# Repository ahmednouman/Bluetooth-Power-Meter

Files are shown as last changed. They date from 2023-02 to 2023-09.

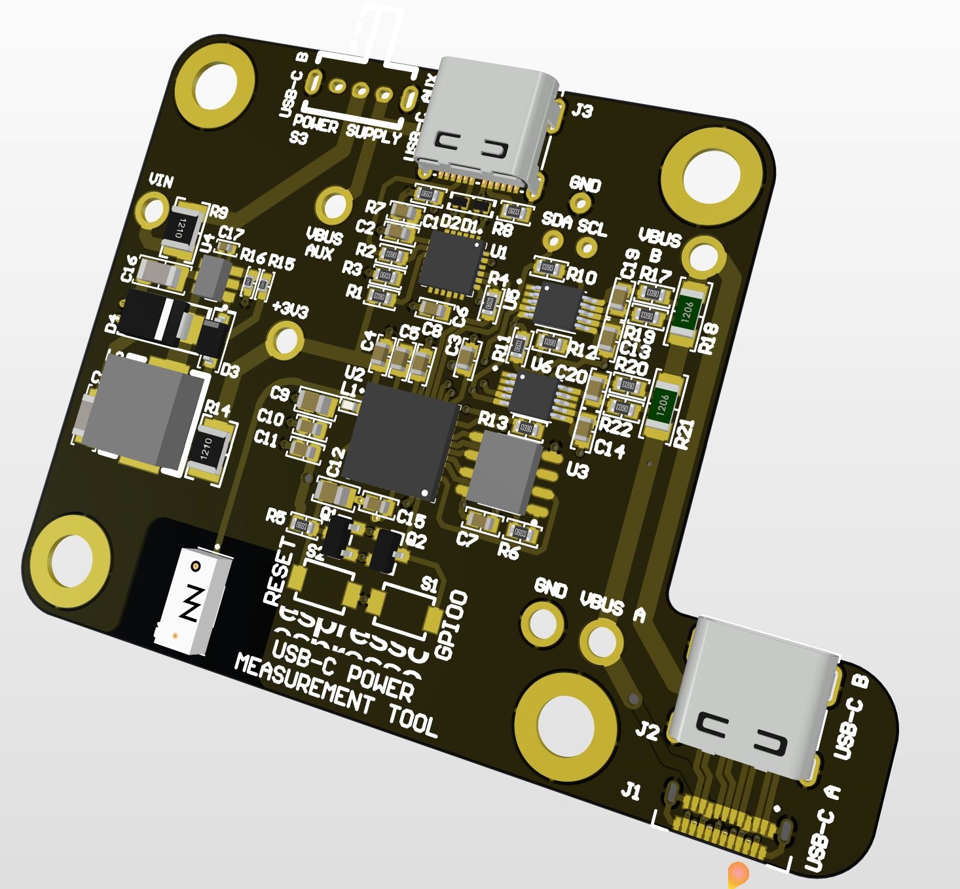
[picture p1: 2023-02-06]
images/3d.png

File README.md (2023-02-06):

# Bluetooth-Power-Meter
This is a 4-layer board (Power meter), designed to measure power(voltage & current) consumption of any USB-C device including USB-C video devices.
developed based on an ESP32-PICO-D4 MCU.
The board features:
- USB-C to USB-C data/video pass through
- Voltage and current measurement chips
- Chip Antenna design

<p align="center">

</p>

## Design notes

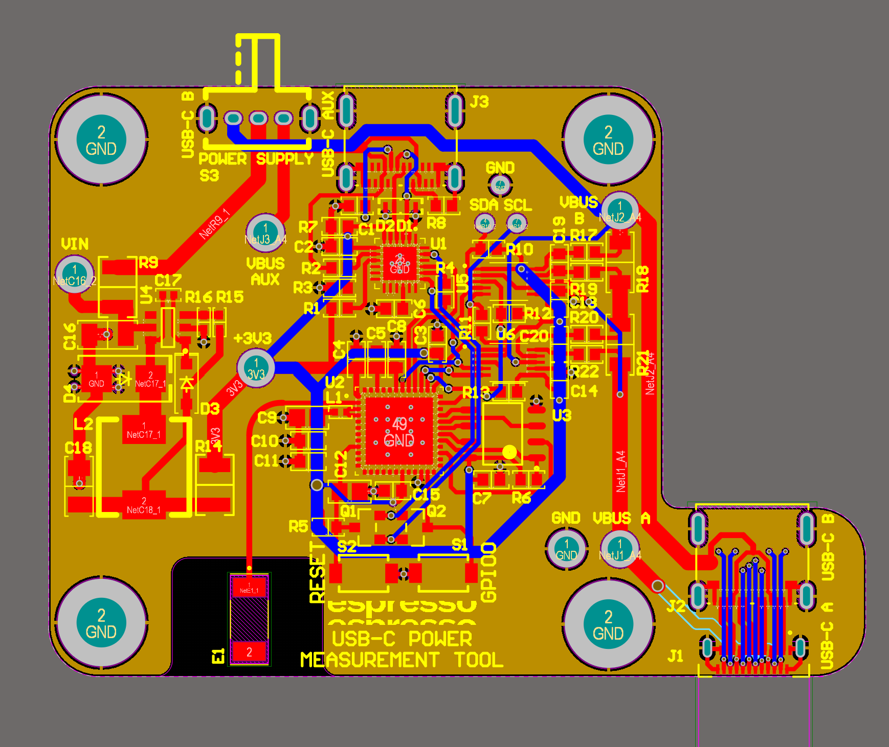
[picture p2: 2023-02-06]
images/tracks.png

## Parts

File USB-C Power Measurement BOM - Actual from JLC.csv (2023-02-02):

Uploaded BOM Data |  |  | Review Matched Parts
Top Designator | Comment | Footprint | Matched Part Detail
C5 | 100pF | CAP0603_1608 | CL10C101JB8NNNCC14858 50V 100pF C0G ±5% 0603 Multil...
C17 | CAPCER10000PF10... | CAPCER10000PF10... | CL05B103KB5NNNCC15195 50V 10nF X7R ±10% 0402 Multil...
R17,R19,R2... | 10Ohms | RES0603_1608 | 0603WAF100JT5EC22859 100mW Thick Film Resistors 75V...
R1 | 4.7kOhms | RES0603_1608 | 0603WAF4701T5EC23162 100MW THICK FILM RESISTORS 75V...
R7,R8 | 5.1kOhms | RES0603_1608 | 0603WAF5101T5EC23186 100MW THICK FILM RESISTORS 75V...
R4 | 510Ohms | RES0603_1608 | 0603WAF5100T5EC23193 100mW Thick Film Resistors 75V...
R2 | 24kOhms | RES0603_1608 | 0603WAF2402T5EC23352 100MW THICK FILM RESISTORS 75V...
R15 | 100kOhms | RES0402_1005 | 0402WGF1003TCEC25741 62.5mW Thick Film Resistors 50...
R5,R6,R10,... | 10kOhms | RES0603_1608 | 0603WAF1002T5EC25804 100MW THICK FILM RESISTORS 75V...
R3 | 47kOhms | RES0603_1608 | 0603WAF4702T5EC25819 100MW THICK FILM RESISTORS 75V...
R16 | 32.4kOhms | RES0402_1005 | 0402WGF3242TCEC26974 62.5MW THICK FILM RESISTORS 50...
C1,C3,C4,C... | 0.1礔 | CAP0603_1608 | 0603B104K500NTC30926 50V 100NF X7R ±10% 0603 MULTI...
C9,C12 | 10礔 | CAP0805_2012 | 0805X106K250NTC40894 25V 10UF X5R ±10% 0805 MULTIL...
U5,U6 | INA226AIDGSR | SOP50P490X110-1... | INA226AIDGSRC49851 MSOP-10 Current-Sensing Ampli...
C6 | 4.7礔 | CAP0603_1608 | 0603X475K100NTC69182 10V 4.7UF X5R ±10% 0603 MULTI...
U4 | RT8258GE | SOT100P279X130-... | RT8258GEC77574 SOT-23-6 DC-DC Converters ROH...
D3 | 1N4148W-TP | SOD-123 | 1N4148W-TPC77978 100V -65℃~+150℃@(Tj) 400mW 1.2...
D1,D2 | LXES15AAA1-153 | 402 | LXES15AAA1-153C86141 4V Bidirectional 0402 ESD Pro...
Q1,Q2 | MMSS8050-H-TP | MCCSEMISOT-23-3 | MMSS8050-H-TPC90158 100nA 300mW 1.5A 200@100mA,1V ...
C2,C7,C8,C... | 1礔 | CAP0603_1608 | 0603B105K500NTC90540 50V 1UF X7R ±10% 0603 MULTILA...
C18 | 22礔 | CAP1206_3216-0.... | 1206X226K160NTC105480 16V 22UF X5R ±10% 1206 MULTIL...
D4 | B230-13-F | DO214AASMB | B230-13-FC110482 30V 500mV@2A 2A SMB(DO-214AA) ...
C16 | 10礔 | CAP1206_3216-0.... | 1206X106K500NTC116702 50V 10UF X5R ±10% 1206 MULTIL...
J2,J3 | 1054500101 | Molex1054500101 | 1054500101C134092 1 24 Female Type-C SMD USB Co...
S3 | SK-12D02-VG5 | SK-12D02-VG5 | SK-12D02-VG5C136722 Lying SPDT 9.5mm PCPin 5000 Re...
U2 | ESP32-PICO-D4 | PQFN50P700X700X... | ESP32-PICO-D4C193707 QFN-48_7x7x05P RF Transceiver...
R9,R14 | 0Ohms | RES1210_3225 | ERJ14Y0R00UC242155 500mW ±200ppm/℃ -55℃~+155℃ 0Ω ...
U3 | LY68L6400 | SOP-8_3.9x4.9x1... | LY68L6400SLITC261881 SOP-8_150mil SRAM ROHS
L1 | FIXEDIND2NH1A50... | IND0402_1005 | 0402CP-2N0G-LRHC346262 1.04A 2NH ±2% 70MΩ 0402 INDUC...
U1 | CP2104-F03-GM | QFN50P400X400X8... | CP2104-F03-GMC430013 QFN-24 USB ICs ROHS
R18,R21 | 2mOhms | STACKPOLECSR120... | HoLR1206-1W-2mR-1%-75ppmC601094 1W 2MΩ ±75PPM/℃ ±1% 1206 CURR...
S1,S2 | GT-TC029B-H025-... | GT-TC029B-H025-... | GT-TC029B-H025-L1NC843669 No NO SMDSplicing 50mA 3.9mm 1...
L2 | 4A10uH�20%67mOS... | 4A10uH�20%67mOS... | TMPC0624H-100M-Z01-DC2880075 3.2A 10uH ±20% 92mΩ 5A SMD,7x6...
E1 | NN01-102 | XCVR_NN01-102 | NN01-102C9900010288 2.45GHz Bluetooth, WLAN, Zigbe...
J1 | USB4155-03-C_RE... | GCT_USB4155-03-... | No part selected Search

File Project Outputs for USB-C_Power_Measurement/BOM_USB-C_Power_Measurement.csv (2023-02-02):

Comment | Description | Designator | Footprint | LibRef | Quantity
0.1 µF | CAP CER 0.1UF 50V X7R 0603 | C1, C3, C4, C11, C13, C14, C15, C19, C20 | CAP 0603_1608 | C0603C104K5RAC7411 | 9
1 µF | CAP CER 1UF 10V X7R 0603 | C2, C7, C8, C10 | CAP 0603_1608 | CC0603KRX7R6BB105 | 4
100 pF | CAP CER 100PF 50V C0G/NP0 0603 | C5 | CAP 0603_1608 | C0603C101K5GACAUTO | 1
4.7 µF | CAP CER 4.7UF 16V X7R 0603 | C6 | CAP 0603_1608 | GRM188Z71C475KE21J | 1
10 µF | CAP CER 10UF 6.3V X7R 0805 | C9, C12 | CAP 0805_2012 | CGA4J1X7R0J106K125AC | 2
10 µF | CAP CER 10UF 25V X7R 1206 | C16 | CAP 1206_3216 - 0.8MM | GRM31CR71E106MA12K | 1
10000 pF | CAP CER 10000PF 10V X7R 0402 | C17 | CAP 0402_1005 | VJ0402Y103JXQCW1BC | 1
22 µF | CAP CER 22UF 6.3V X7R 1206 | C18 | CAP 1206_3216 - 0.8MM | GCM31CR70J226KE23L | 1
LXES15AAA1-153 | TVS DIODE 4V 1005 | D1, D2 | 0402 | LXES15AAA1-153 | 2
1N4148W-TP | DIODE GEN PURP 100V 150MA SOD123 | D3 | SOD-123 | 1N4148W-TP | 1
B230-13-F | DIODE SCHOTTKY 30V 2A SMB | D4 | DO214AA SMB | B230-13-F | 1
NN01-102 | 2.45GHz Bluetooth, WLAN, Zigbee Chip RF Antenna 2.4GHz ~ 2.5GHz 1.7dBi Solder Surface Mount | E1 | XCVR_NN01-102 | NN01-102 | 1
USB4155-03-C_REVA |  | J1 | GCT_USB4155-03-C_REVA | USB4155-03-C_REVA | 1
1054500101 | CONN RCP USB3.1 TYPEC 24P SMD RA | J2, J3 | Molex 1054500101 | 1054500101 | 2
2 nH | FIXED IND 2NH 1A 50 MOHM SMD | L1 | IND 0402_1005 | MHQ1005P2N0BT000 | 1
10uH | 4A 10uH ±20% 67mO SMD,7x6.6x2.8mm Power Inductors ROHS | L2 | 0630CDMCCDS-100MC | 0630CDMCCDS-100MC | 1
MMSS8050-H-TP | TRANS NPN 25V 1.5A SOT23 | Q1, Q2 | MCCSEMI SOT-23-3 | MMSS8050-H-TP | 2
4.7 kOhms | RES SMD 4.7K OHM 1% 1/10W 0603 | R1 | RES 0603_1608 | RT0603FRE074K7L | 1
24 kOhms | RES 24K OHM 1% 1/10W 0603 | R2 | RES 0603_1608 | RK73H1JTTD2402F | 1
47 kOhms | RES SMD 47K OHM 1% 1/10W 0603 | R3 | RES 0603_1608 | RT0603FRE0747KL | 1
510 Ohms | RES 510 OHM 5% 1/10W 0603 | R4 | RES 0603_1608 | RMCF0603JT510R | 1
10 kOhms | RES SMD 10K OHM 5% 1/4W 0603, RES 10K OHM 0.1% 1/16W 0603 | R5, R6, R10, R11, R12, R13 | RES 0603_1608 | RCS060310K0JNEA, RNCS0603BKE10K0 | 6
5.1 kOhms | RES 5.1K OHM 5% 1/10W 0603 | R7, R8 | RES 0603_1608 | RK73B1JTTD512J | 2
0 Ohms | RES 0 OHM JUMPER 1/2W 1210 | R9, R14 | RES 1210_3225 | RC1210JR-070RL | 2
100 kOhms | RES 100K OHM 0.1% 1/10W 0402 | R15 | RES 0402_1005 | RP73PF1E100KBTD | 1
32.4 kOhms | RES SMD 32.4KOHM 0.1% 1/16W 0402 | R16 | RES 0402_1005 | CPF0402B32K4E1 | 1
10 Ohms | RES SMD 10 OHM 0.1% 1/10W 0603 | R17, R19, R20, R22 | RES 0603_1608 | CRT0603-BY-10R0ELF | 4
2 mOhms | 1W 0.002 OHMS 1% 1206 | R18, R21 | STACKPOLE CSR1206 | PCS1206FR0020ET | 2
GT-TC029B-H025-L1N | No NO SMDSplicing 50mA 3.9mm 100MO 100000 12V 250gf@±30gf 2.9mm -30?~+85? 2.5mm Black Round Button Brick nogging SPST SMD Tactile Switches ROHS | S1, S2 | GT-TC029B-H025-L1N | GT-TC029B-H025-L1N | 2
SK-12D02-VG5 | Lying SPDT 9.5mm PCPin 5000 Rectangular columnar -25?~+70? Plugin Slide Switches ROHS SP#C136722 | S3 | SK-12D02-VG5 | SK-12D02-VG5 | 1
CP2104-F03-GM | USB-to-UART 1-CH 576byte FIFO 3.3V 24-Pin QFN EP T/R | U1 | QFN50P400X400X80-25N | CP2104-F03-GM | 1
ESP32-PICO-D4 | Bluetooth, WiFi 802.11b/g/n, Bluetooth v4.2 +EDR, Class 1, 2 and 3 Transceiver Module 2.4GHz ~ 2.5GHz Surface Mount | U2 | PQFN50P700X700X104-49N | ESP32-PICO-D4 | 1
LY68L6400 | 64M Bits Serial Pseudo-SRAM with SPI and QPI | U3 | SOP-8_3.9x4.9x1.27P | LY68L6400SLIT | 1
RT8258GE | RICHTEK 1.2A, 24V, 700kHz Step-Down Converter SOT23-6 | U4 | SOT100P279X130-6N | RT8258GE | 1
INA226AIDGSR |  | U5, U6 | SOP50P490X110-10N | INA226AIDGSR | 2

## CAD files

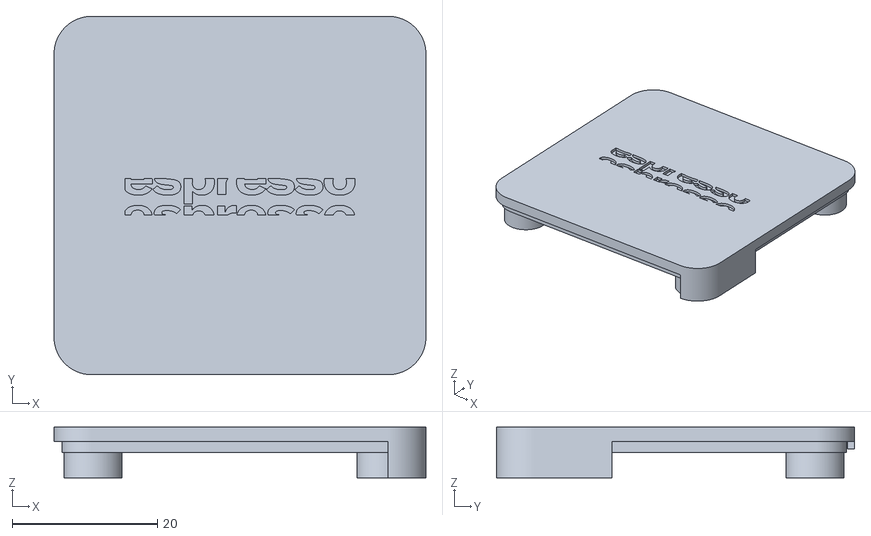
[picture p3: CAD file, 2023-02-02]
PCB_Power_Measurement_2.stl
51.2 x 49.4 x 7.00

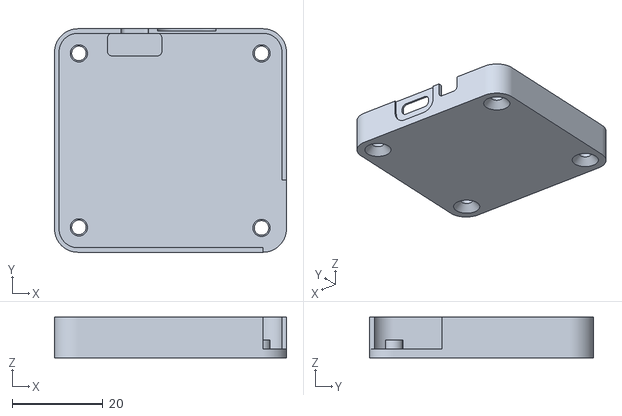
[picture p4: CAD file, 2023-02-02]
PCB_Power_Measurement_1.stl
51.2 x 49.4 x 9.00

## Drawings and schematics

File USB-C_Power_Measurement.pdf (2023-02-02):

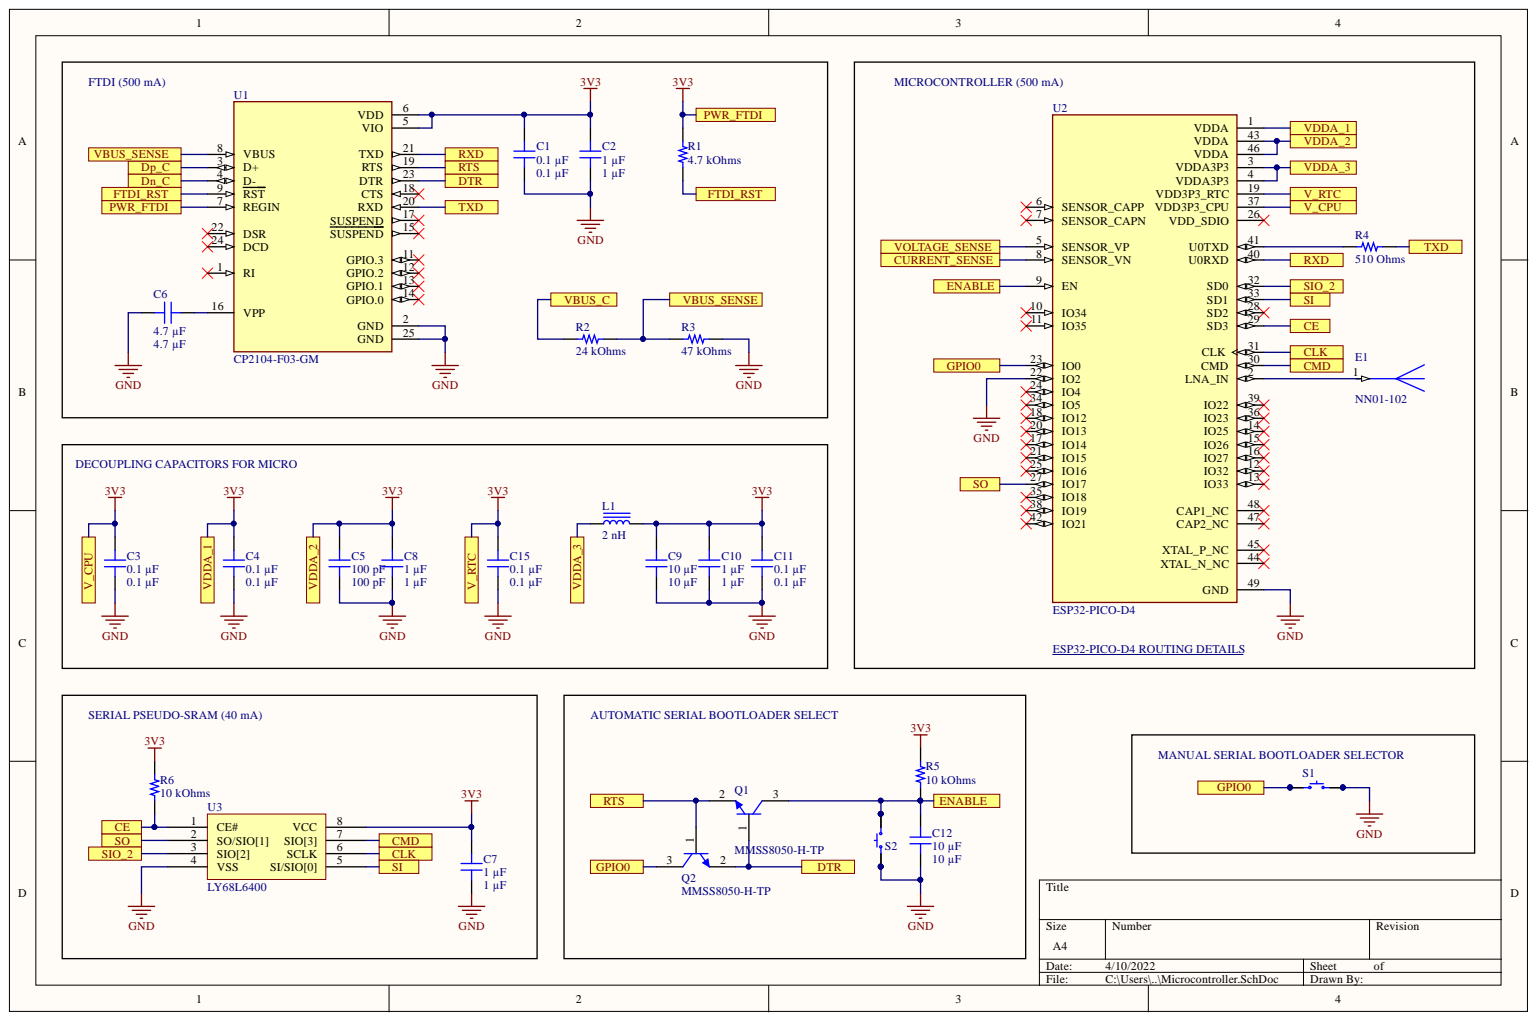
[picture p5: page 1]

DECOUPLING CAPACITORS FOR MICRO

SERIAL PSEUDO-SRAM (40 mA)

AUTOMATIC SERIAL BOOTLOADER SELECT

MANUAL SERIAL BOOTLOADER SELECTOR

SO | CMD
SIO_2 | CLK

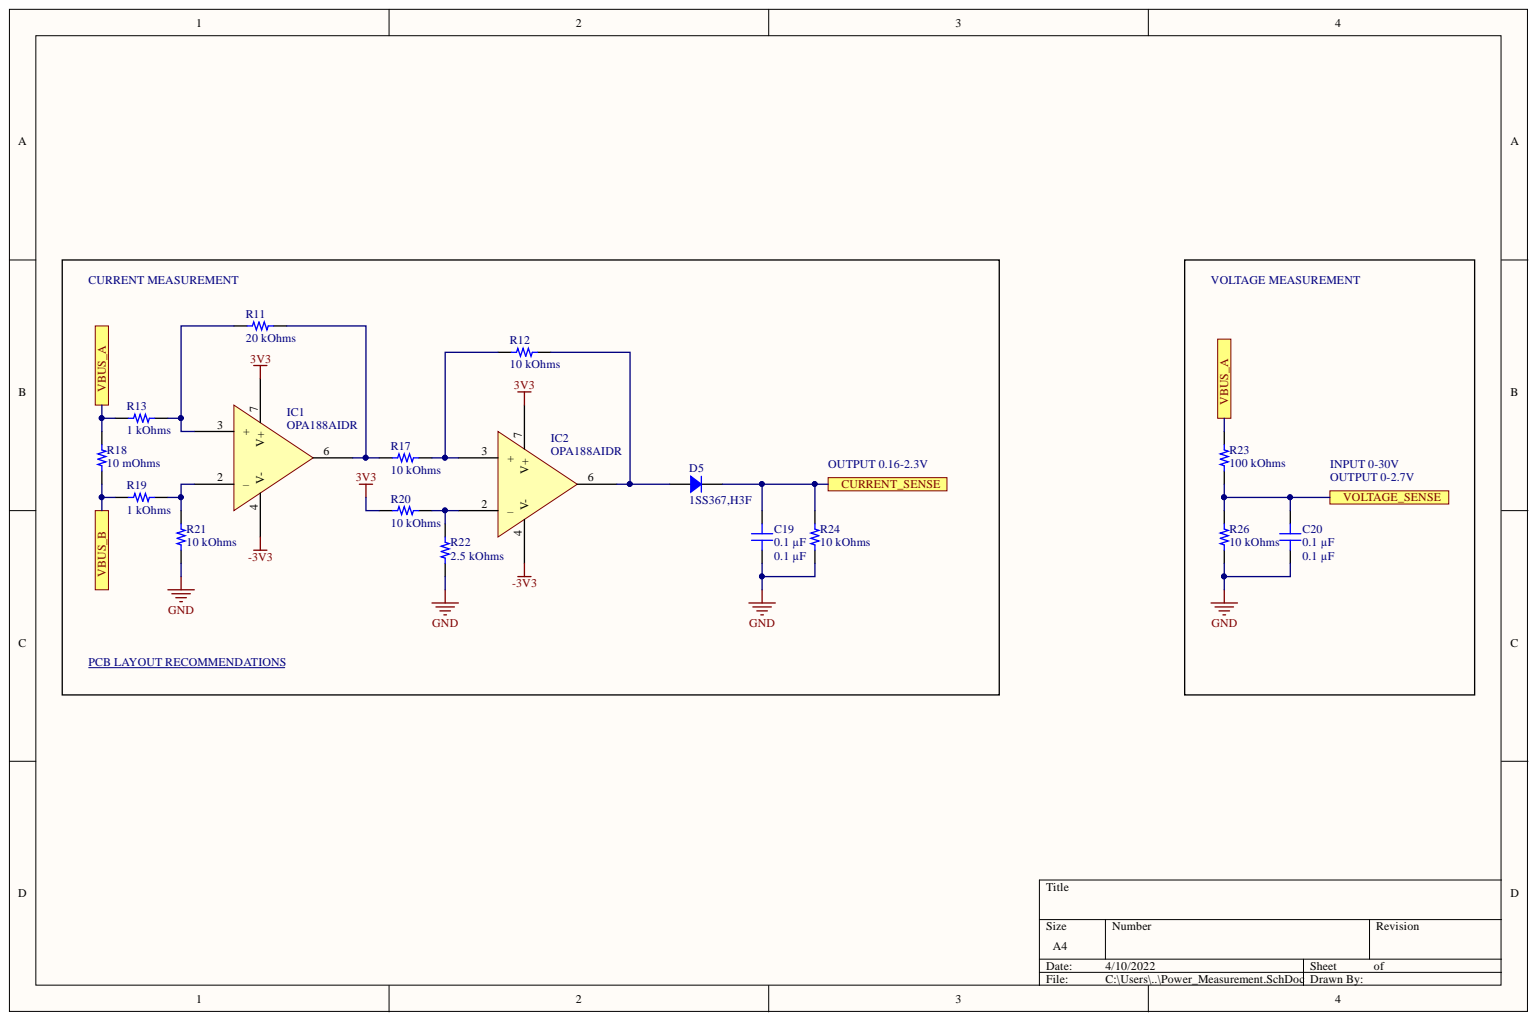
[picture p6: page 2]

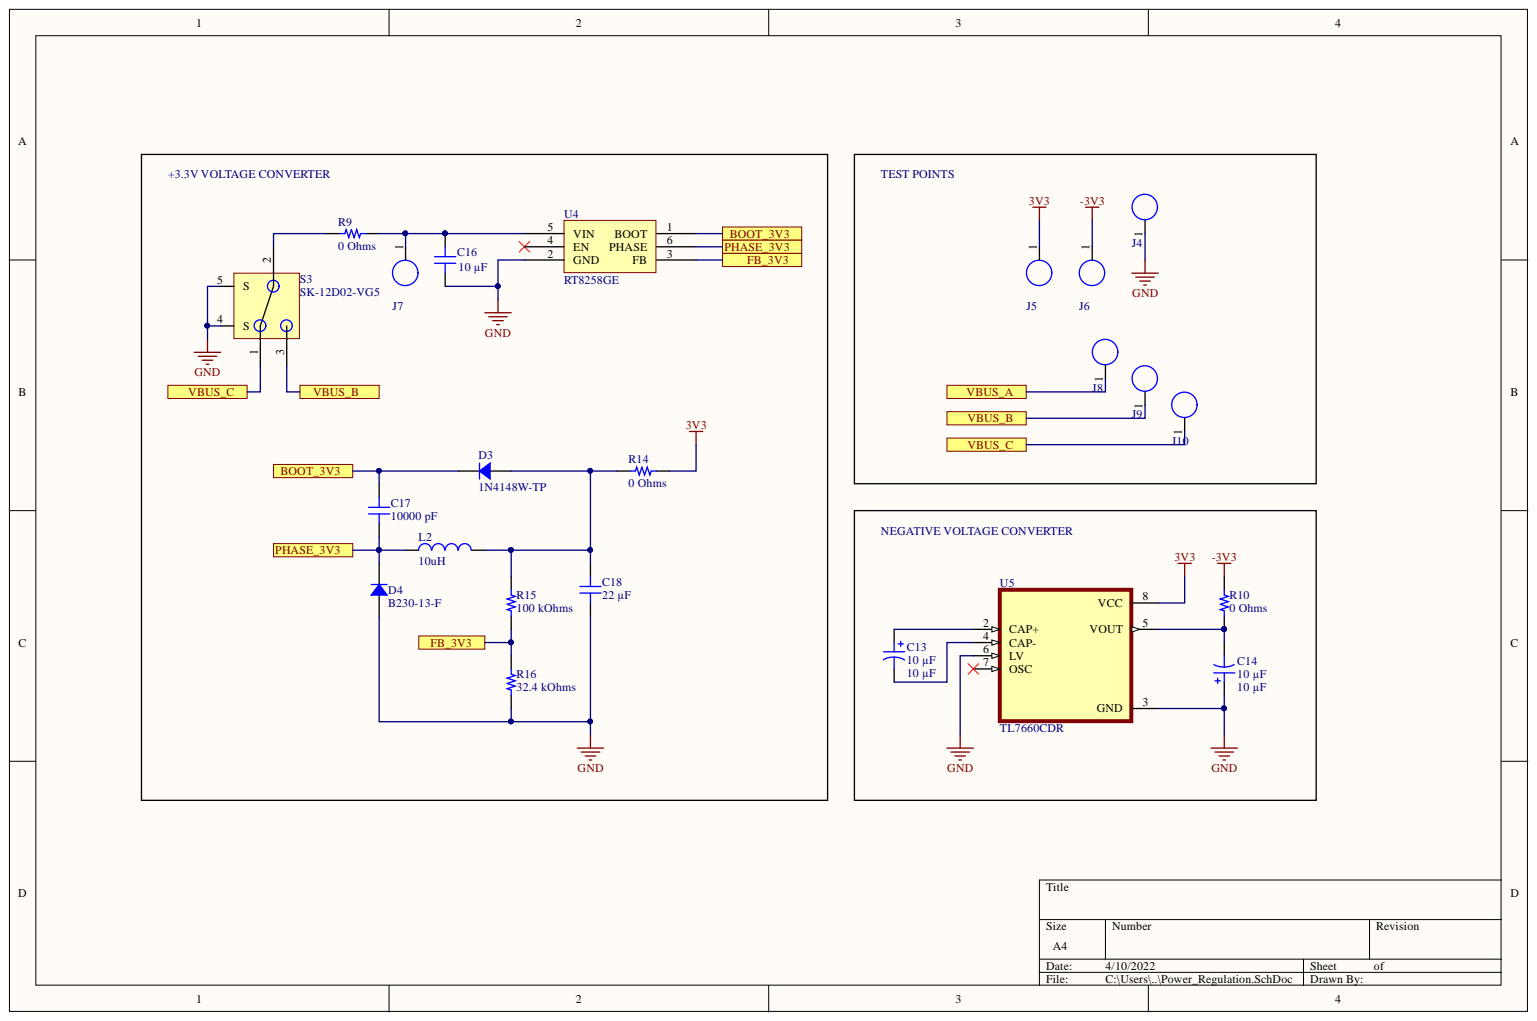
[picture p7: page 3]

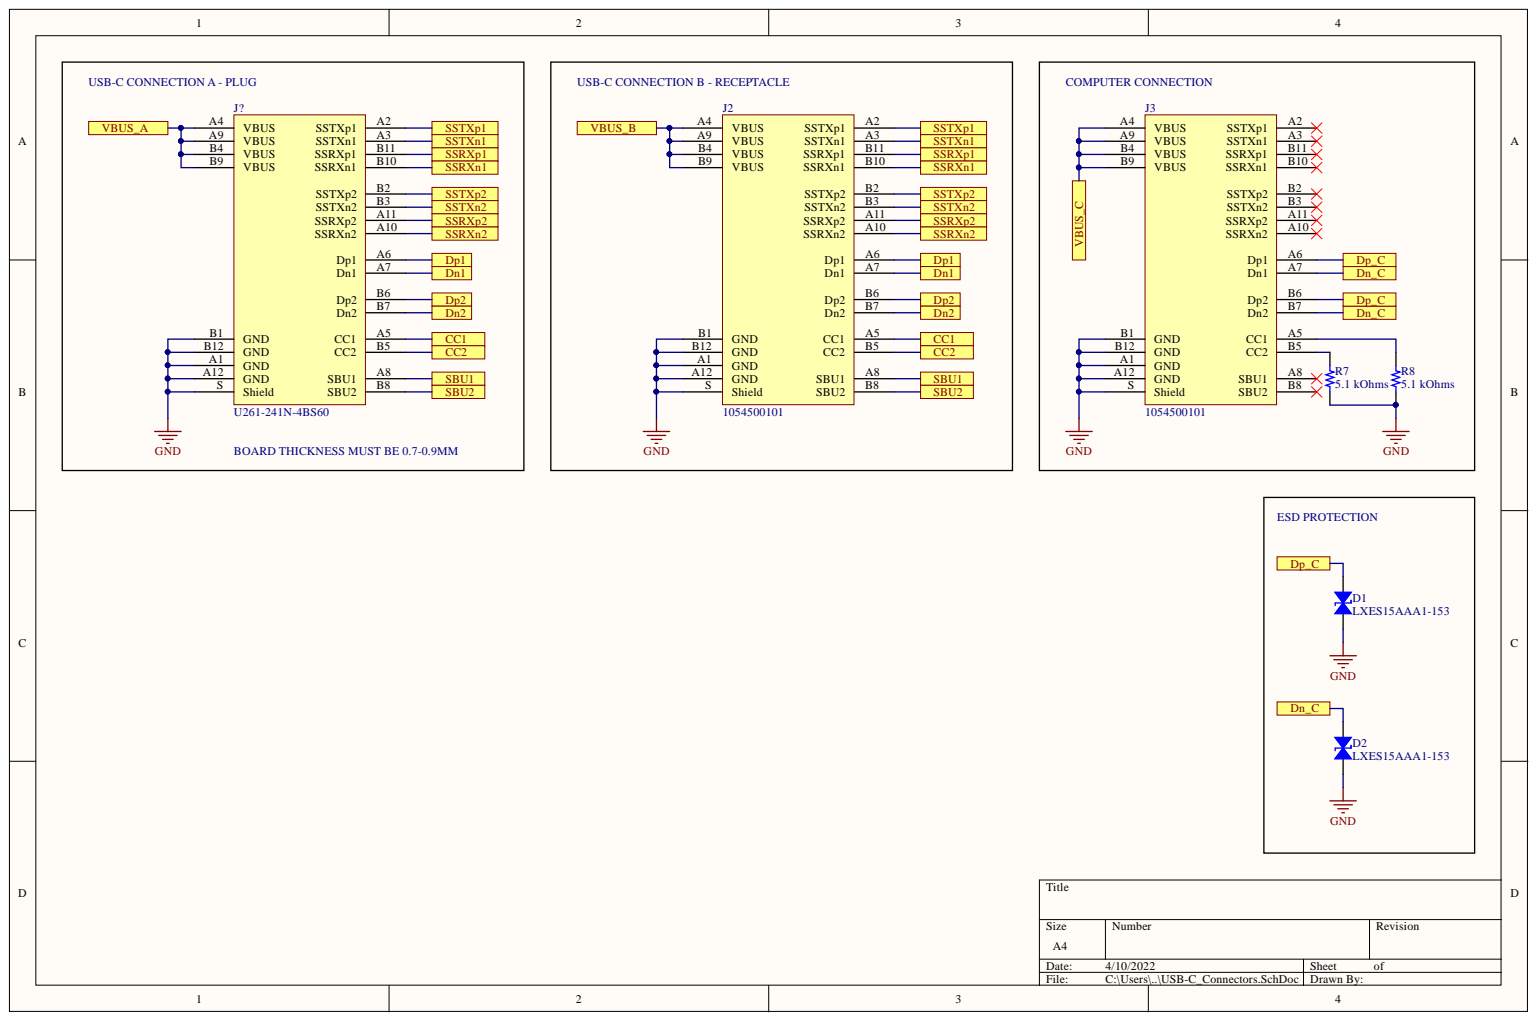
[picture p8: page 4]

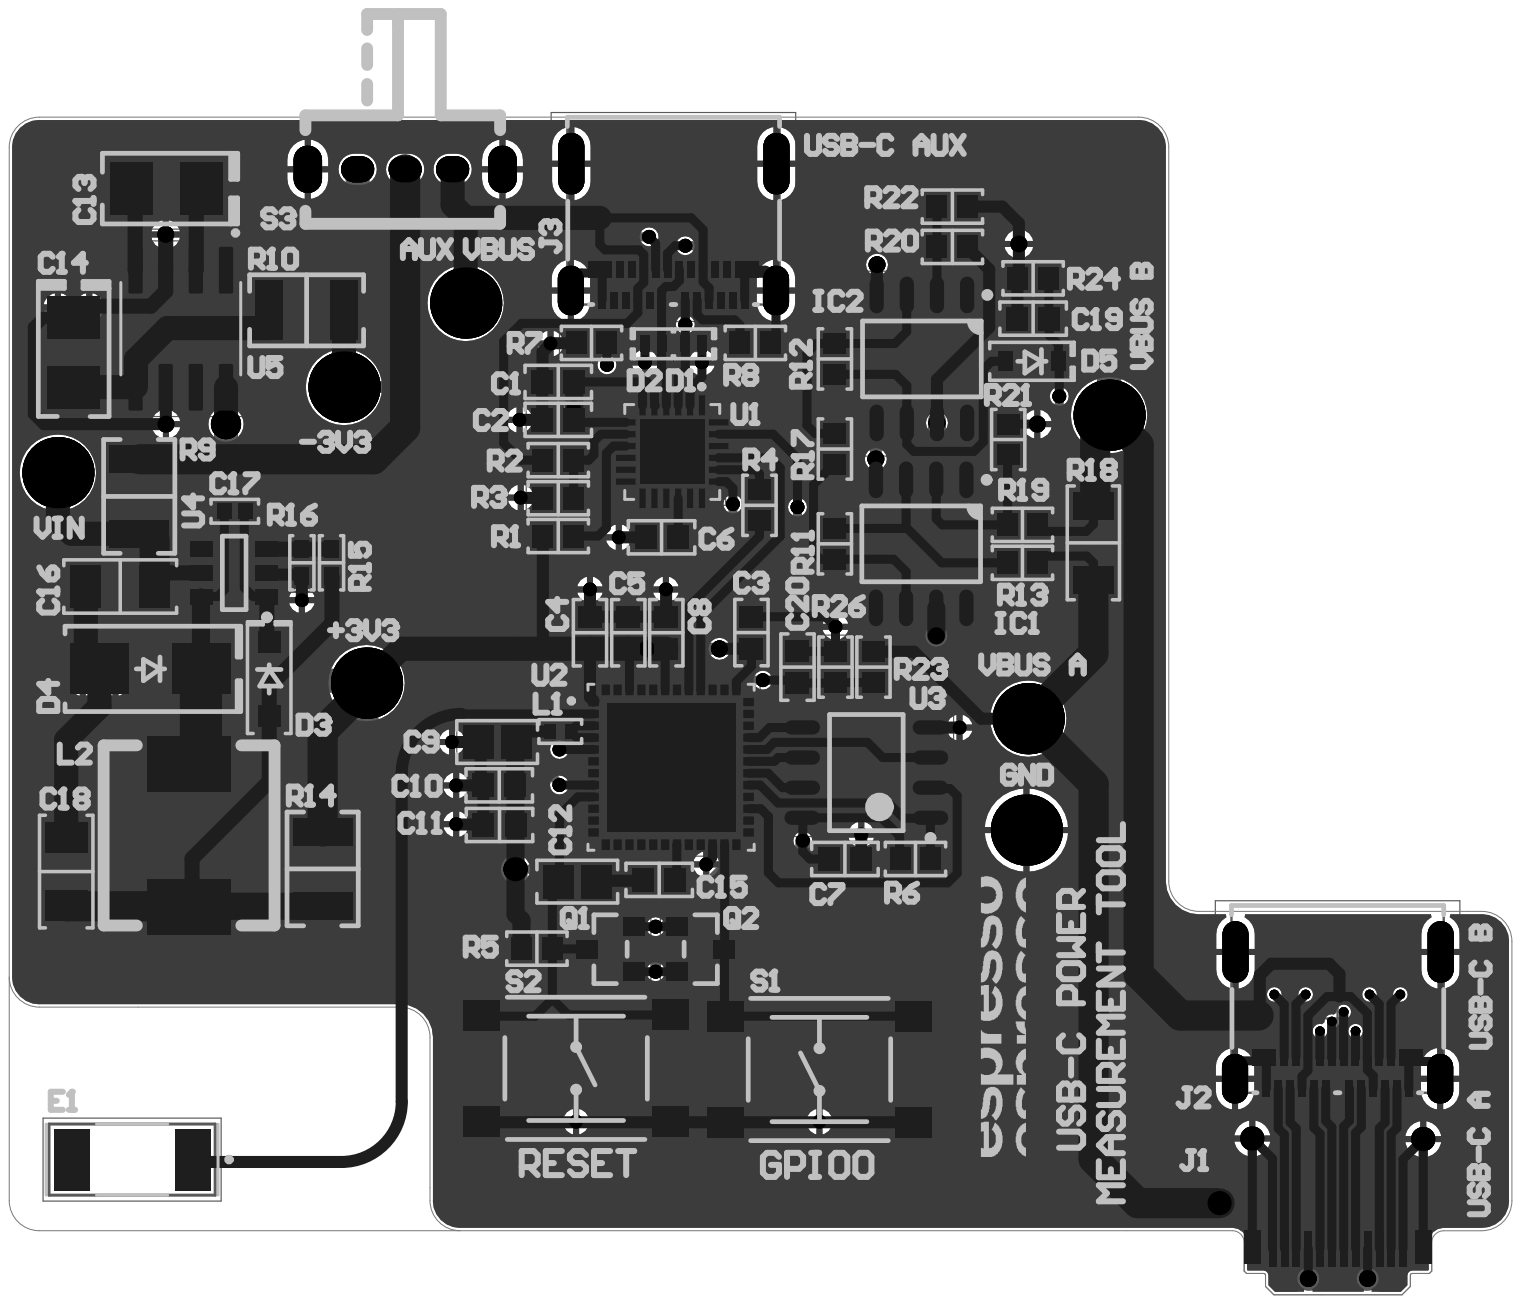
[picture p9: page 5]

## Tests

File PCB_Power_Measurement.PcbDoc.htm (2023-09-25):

Reporting Options

# File in Previous Format

Date | : | 7/1/2023
Time | : | 1:39:22 PM
Filename | : | C:\Espresso\PersonalHub\Bluetooth-Power-Meter\PCB_Power_Measurement.PcbDoc

Version | Warning

This file was generated by an earlier version of the software

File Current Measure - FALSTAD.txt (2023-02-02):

$ 1 0.000005 10.20027730826997 50 5 43 5e-11
r 32 192 32 272 0 0.01
w 32 128 32 192 1
w 336 208 336 128 0
w 208 128 112 128 0
w 112 128 112 192 0
r 112 192 32 192 0 1000
r -32 224 -32 336 0 4
w 32 272 32 336 0
r 336 128 208 128 0 20000
w 336 208 464 208 3
r 32 272 112 272 0 1000
w 112 224 112 272 0
r 112 272 112 352 0 10000
g 112 352 112 400 0 0
409 224 208 320 208 1 0.8 -1.424897561023406 0.016 0
w 112 192 224 192 3
w 112 224 224 224 3
w 320 208 336 208 0
R 272 320 272 352 0 0 40 -3.3 0 0 0.5
w 272 240 272 320 1
R 272 176 272 144 0 0 40 3.3 0 0 0.5
v -32 128 -32 224 0 0 40 30 0 0 0.5
409 544 224 704 224 1 0.8 -5.297524655984678 0.016 0
R 624 192 624 144 0 0 40 3.3 0 0 0.5
R 624 320 624 352 0 0 40 -3.3 0 0 0.5
r 368 240 432 240 0 10000
r 544 240 544 336 0 2500
g 544 336 544 368 0 0
R 368 240 336 240 0 0 40 3.3 0 0 0.5
r 464 208 544 208 0 10000
w 544 208 544 96 0
r 544 96 704 96 0 10000
w 704 96 704 224 0
w -32 336 32 128 0
w -32 128 32 336 0
w 624 256 624 320 1
r 800 224 800 304 0 10000
g 800 304 800 336 0 0
w 432 240 544 240 3
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
34 1SS357,H3F 0 0.000019999999999999998 0.084 1.7699694593 10 0
d 752 224 800 224 2 1SS357,H3F
w 704 224 752 224 3
o 41 16 0 4099 2.5 0.00009765625 0 2 41 3

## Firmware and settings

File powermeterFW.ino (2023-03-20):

#include "INA226.h"
#include "Wire.h"

#include <BLEDevice.h>
#include <BLEUtils.h>
#include <BLEServer.h>
#include <BLEAdvertising.h>

INA226 INA(0x45);

char txValue = 0;
float voltage = 0;
float current = 0;
float wattage = 0;

#include "esp_err.h"
#include "esp_pm.h"
#include "driver/timer.h"

#define SERVICE_UUID        "4fafc201-1fb5-459e-8fcc-c5c9c331914b"
#define CHARACTERISTIC_UUID "beb5483e-36e1-4688-b7f5-ea07361b26a8"
#define ONBOARD_LED 32
#define ONBOARD_SWITCH 26
#define BLETIMEOUT 5*60 //Seconds

BLECharacteristic *pCharacteristic;
BLEServer *pServer;
BLEService *pService;

uint8_t value[1] = {0};
volatile bool deviceConnected = false;
volatile bool buttonPressed = false;

esp_pm_config_esp32_t pm_config = {
  .max_freq_mhz = 80, // e.g. 80, 160, 240
  .min_freq_mhz = 40, // e.g. 40
  .light_sleep_enable = true,
};

hw_timer_t * timer = NULL;
portMUX_TYPE timerMux = portMUX_INITIALIZER_UNLOCKED;

void resetTimer(){
  portENTER_CRITICAL_ISR(&timerMux);
  timerRestart(timer);
  portEXIT_CRITICAL_ISR(&timerMux);
}

class MyServerCallbacks: public BLEServerCallbacks {
  void onConnect(BLEServer* pServer) {
    deviceConnected = true;
    resetTimer();
  };

  void onDisconnect(BLEServer* pServer) {
    deviceConnected = false;
    BLEDevice::startAdvertising();
    resetTimer();
  };
};

class MyCallbacks: public BLECharacteristicCallbacks {
  void onWrite(BLECharacteristic *pCharacteristic) {
    Serial.println("OnWrite");
  
    std::string value = pCharacteristic->getValue();
  
    if (value.length() > 0) {
      Serial.println("*********");
      Serial.print("New value: ");
      for (int i = 0; i < value.length(); i++)
        Serial.print(value[i]);
  
      Serial.println();
      Serial.println("*********");
    }
  }
};

void IRAM_ATTR switchPressToggle(){
  if (deviceConnected) {
    if (digitalRead(ONBOARD_SWITCH) == LOW) {
        digitalWrite(ONBOARD_LED, HIGH);
        buttonPressed = true;
        value[0] = 1;
        pCharacteristic->setValue(&value[0], 1);
        pCharacteristic->notify();
    } else {
        digitalWrite(ONBOARD_LED, LOW);
        buttonPressed = false;
        value[0] = 0;
        pCharacteristic->setValue(&value[0], 1);
        pCharacteristic->notify();
    }
  } else {
    digitalWrite(ONBOARD_LED, LOW);
    BLEDevice::startAdvertising();
  }
  resetTimer();
}

void setup() {
  Serial.begin(115200);
  
  Wire.begin();
  if (!INA.begin() )
  {
    Serial.println("could not connect. Fix and Reboot");
  }
  INA.setMaxCurrentShunt(1, 0.002);
  
  pinMode(ONBOARD_LED, OUTPUT);
  digitalWrite(ONBOARD_LED, LOW);

  esp_ble_tx_power_set(ESP_BLE_PWR_TYPE_DEFAULT, ESP_PWR_LVL_N12); 
  esp_ble_tx_power_set(ESP_BLE_PWR_TYPE_ADV, ESP_PWR_LVL_N12);
  esp_ble_tx_power_set(ESP_BLE_PWR_TYPE_SCAN ,ESP_PWR_LVL_N12);
  
  esp_pm_configure(&pm_config);
  esp_sleep_pd_config(ESP_PD_DOMAIN_RTC_PERIPH, ESP_PD_OPTION_ON);
  esp_sleep_enable_ext0_wakeup(GPIO_NUM_26, LOW);
  timer = timerBegin(0, 80, true);
  timerAttachInterrupt(timer, &onTimer, true);
  timerAlarmWrite(timer, 1000000*BLETIMEOUT, true);
  timerAlarmEnable(timer);
  
  //Initialise button state
  pinMode(ONBOARD_SWITCH, INPUT);
  switchPressToggle();
  attachInterrupt(digitalPinToInterrupt(ONBOARD_SWITCH), switchPressToggle, CHANGE);
  
  BLEDevice::init("espressoPowerMeter Device");
  pServer = BLEDevice::createServer();
  pServer->setCallbacks(new MyServerCallbacks());
  pService = pServer->createService(SERVICE_UUID);

  pCharacteristic = pService->createCharacteristic(
                                         CHARACTERISTIC_UUID,
                                         BLECharacteristic::PROPERTY_READ |
                                         BLECharacteristic::PROPERTY_WRITE |
                                         BLECharacteristic::PROPERTY_NOTIFY
                                       );

  pCharacteristic->setValue("");
  pCharacteristic->setCallbacks(new MyCallbacks());
  pService->start();
  
  BLEAdvertising *pAdvertising = BLEDevice::getAdvertising();
  pAdvertising->addServiceUUID(SERVICE_UUID);
  pAdvertising->setScanResponse(true);
  pAdvertising->setMinPreferred(0x06);
  
  BLEAdvertisementData pAdvertisementData = BLEAdvertisementData();
  pAdvertisementData.setManufacturerData((std::string)"espresso Displays");
  pAdvertisementData.setName((std::string)"espressoPowerMeter");
  pAdvertising->setAdvertisementData(pAdvertisementData);
  
  BLEDevice::startAdvertising();

}

void loop() {
  if(deviceConnected)
  {
    voltage = INA.getBusVoltage();
    current = INA.getCurrent_mA();
    wattage = voltage * (current/1000) ;
    char txString[100];
    
    sprintf(txString, "[V%.2f][C%.2f][W%.2f]", voltage, current, wattage);

    pCharacteristic->setValue(txString);
    pCharacteristic->notify();

    delay(1000);
    
  }
}

void onTimer() {
  portENTER_CRITICAL_ISR(&timerMux);
  deviceConnected = false;
  timerAlarmDisable(timer);
  esp_light_sleep_start();
  portEXIT_CRITICAL_ISR(&timerMux);
}
